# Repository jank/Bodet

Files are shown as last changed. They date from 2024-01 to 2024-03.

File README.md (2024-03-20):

# Bodet / T&N Flip Clock

I found a T&N (Telefonbau & Normalzeit) flip clock from the late 70ies/early 80ies. The clock is branded as T&N but was produced by Bodet.The model sticker on the inside says BT637.

I was inspired by this [Hackaday project](https://hackaday.io/project/186457-bodet-flip-clock-hacked-back-to-the-present) by iSax.

In this repo I documented the process on how I restored the clock and I also share design files and code.

## The Plan

- [x] check the clock is working: I connected the clock to a 12V power supply. Flipping + and - caused the clock to advance by one minute. So I considered it fully functional.

- [x] create spare tiles: I experimented with hard paper and plexiglas. In the end a rigid PVC material worked best. Cut out tiles using a Cricut.

- [x] program micro controller as clock driver: the code is ready. I added support for timezone and DST changes. When changing to DST, the clock will advance by 60 minutes, when changing to normal time, the clock will delay an hour.

- [ ] solder all parts together: Provide power from 230V AC, wire up and solder 230V AC to 12V DC converter, ESP32, and H-Bridge to drive clock.

## Implementing the Plan

As any good plan, mine changed as it was confronted with reality. I wrote down the different steps and detours I took. It might help you or my future self to avoid some detours.

### Check the Clock is Working

This was straight forward. Hooked up the clock to 12V supply and switched + and -. When the direction of the current was changed (flip +/-) the clock advanced by one minute.

The mechanics to drive the hour from the minute, the weekday and day of month from the hour, and the month from the day of month all worked. I did not check the leap year function. Will do that once all is wired up.

Seven of the hour and two of the minute tiles were missing.

### Create Spare Tiles

I first tried to get spare tiles from Bodet. To no surprise, they do not have them on stock anymore.

I used Fusion360 to design the tile (hour and minute tiles are identical for my clock). You can find the [Flip Clock Spare Part.dxf](/Spare%20Tiles/Flip%20Clock%20Spare%20Part.dxf) file in this repository.

Finding the right material for the tiles was a bit of a challenge. I found a local company, [Hema Kunststoff GmbH](https://maps.app.goo.gl/DWzyLc1jadHfFmLP6), specialized in milling plastic materials. They were very helpful in identifying the material: hard paper. It is a fiber composite material made of paper and a phenol-formaldehyde resin (phenolic resin).

I tried laser cutting the hard paper in a local maker space. Unfortunately, this did not work out. The power required to cut the material made it impossible to cut out the fine structure required to slot the tile into the clock wheel. This part is only 1mm thick. 

Next I tried to cut the tiles with a Cricut Air 2. But the hard paper was too rigid and the Cricut did not manage to cut through.

I asked the experts at Hema again. They would have milled the pieces for me, but given the required work hours, it would have cost around 10€ per tile.

After more research on the internet, I ordered the [rigid-PVC](https://www.modulor.de/en/rigid-pvc-opaque-coloured.html) from Modulor. This is a black, 0.3 mm thick material. It turned out to have similar flexibility/stiffness as the hard paper and I was able to cut it with the Cricut.

### Putting Numbers on the Spare Tiles.

On the internet I found the font 'folio' as recommendation for Bodet flip tiles. Doing test cuts, it quickly became apparent, that none of the myriads of fonts will do. The numbers of hours and minutes are of different size and slightly different shape. I have the impression, that these printing templates were rather hand-crafted based on a sans-serif template.

My wife helped me out here. She scanned tile that had parts of the missing numbers and reconstructed the shape in the Cricut design program. This required a lot of patience and I am happy that she took over.

We neded up picking white adhesive labels as the material to cut out the numbers. The result is quite impressive. From about a meter distance, it is impossible to distinguish the original tiles from the spare tiles.

### Control the Slave Clock

Due to the lack of a matching master clock, I want to run my slave clock using a microcontroller. 

My rough idea for the algorithm was:

* setup()
  * connect to wifi
  * connect to NTP server to keep system clock in sync

* loop() (e.g. every second)
  * check if a minute passed - remember result
  * check if DST switch happend, if yes, add or subtract 60 from tile buffer
  * if minute passed & tile buffer = 0
    * advance clock
  * if minute passed & tile buffer < 0
    * tile buffer++ // the wall clock is ahead of system time
  * if tile buffer > 0
    * advance clock // the wall clock is behind system time

Based on this [project](https://hackaday.io/project/186457-bodet-flip-clock-hacked-back-to-the-present) I purchased the following equipment for version 1:

* AZ-ATmega328DIP-Board Mikrocontroller Board ATmega16U2 8-bit Dev Board
* Prototyping Prototype Shield Mini Breadboard for UNO R3 (came with bundle)
* Jumper Wire cables M2M/ F2M / F2F 
* Double H-Bridge DC Motor Controller Board Modul AZ-L298N
* 220V AC/DC to 12V DC Mini converter

I was intruiged by the capability to run the board on 12V. That is also the current required to drive the clock motor and the H-Bridge. But I must have been a bit tired when I hit purchase. The ATmega board does not have WiFi on-board. Instead of buying a WiFi shield or a real-time-clock I decided to change to this option:

* ESP32 NodeMCU Module WLAN WiFi Development Board | Dev Kit C V2
* Jumper Wire cables M2M/ F2M / F2F 

Luckily, the H-Bridge provides a 5V power out pin. So I can connect the DC Mini converter to the H-Bridge and power the ESP32 from the 5V output. No need for an additional step-down component.

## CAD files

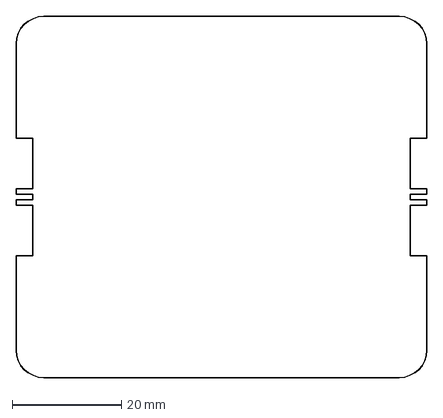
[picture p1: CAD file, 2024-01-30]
Bodet Flip Clock Double Tile.dxf
75.0 x 66.0 mm

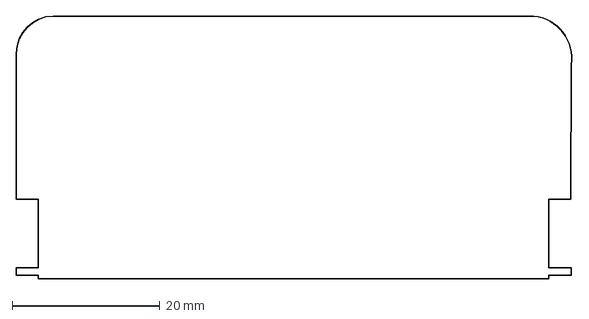
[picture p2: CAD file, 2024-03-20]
Spare Tiles/Flip Clock Spare Part.dxf
75.3 x 35.5 mm

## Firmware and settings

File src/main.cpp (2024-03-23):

#include <Arduino.h>
#include <WiFi.h>

// Mode configuration - uncomment to run in bare bone mode
// will advance the tile every 2.5 sec.
//#define BARE_BONE_MODE

// Log configuration - comment out to get rid of any serial out
#define DEBUG_ENABLED
#ifdef DEBUG_ENABLED
#define DEBUG_PRINTLN(x) Serial.println(x)
#define DEBUG_PRINT(x) Serial.print(x)
#else
#define DEBUG_PRINTLN(x)
#define DEBUG_PRINT(x)
#endif

// Board parameters
static const int enable_pin = 21;
static const int input1_pin = 23;
static const int input2_pin = 22;

// WiFi parameters
static const char *ssid = "Alternativlos";
static const char *password = "Mannheim";

// NTP parameters
static const char *ntp_pool = "de.pool.ntp.org";
static const char *cet_tz = "CET-1CEST,M3.5.0/02,M10.5.0/03";

/** Global varibales */
bool setup_completed = false;
// used to alternate DC flow
bool direction = false;
// Keeps the number of flips to perform on the minute tile to adjust for DST changes.
// Values can be positive, 0, or negativ.
// It is assumed that the main loop is performed at a higher frequency than a minute (e.g. once every 500ms)
// Positive values indicate the number of minutes to advance the clock.
// A 0 indicates that the clock does not need to get changed.
// Negative values indicate that the clock must be paused for -n minutes.
// Positive values larger than one and negative values can be used to perform summer/winter time adjustment.
int dst_adjustment = 0;
// keeps the last time assumed to be displayed on clock
struct tm clock_time;

/**
 * Setup NTP and set local time zone
 */
void initTime(String timezone)
{
  struct tm timeinfo;

  DEBUG_PRINTLN("Setting up time");
  // First connect to NTP server, with 0 TZ offset
  configTime(0, 0, ntp_pool);
  int ntp_retries = 3;
  while (ntp_retries > 0)
  {
    if (!getLocalTime(&timeinfo))
    {
#ifdef DEBUG_ENABLED
      Serial.println("  Failed to obtain time");
      Serial.print("  Retry attempts left: ");
      Serial.println(ntp_retries);
#endif
      ntp_retries -= 1;
    }
    else
    {
#ifdef DEBUG_ENABLED
      Serial.println("  Got time from NTP");
      Serial.printf("  Setting Timezone to %s\n", timezone.c_str());
#endif
      // Set the timezone
      setenv("TZ", timezone.c_str(), 1);
      tzset();
      break;
    }
  }
}

// Function to alternate the direction of current to drive the clock motor
void advanceMinuteTile()
{
  direction = !direction;
#ifdef DEBUG_ENABLED
  if (direction)
  {
    Serial.println("DC >>>");
  }
  else
  {
    Serial.println("DC <<<");
  }
#endif
  digitalWrite(input1_pin, direction);
  digitalWrite(input2_pin, !direction);
  digitalWrite(enable_pin, HIGH); // Enable the motor
}

/**
 * Setup Bodet Clock Driver
 */
// cppcheck-suppress unusedFunction
void setup()
{
  Serial.begin(115200);
  // Initializte the GPIO pins as output and set voltage
  pinMode(enable_pin, OUTPUT);
  pinMode(input1_pin, OUTPUT);
  pinMode(input2_pin, OUTPUT);
  //better without? advanceMinuteTile();
  // just plugin in clock a few seconds after the minute switched to what is shown on the clock.

#ifdef BARE_BONE_MODE
  return;
#endif

  // Connect to WiFi network
  WiFi.begin(ssid, password);
  DEBUG_PRINT("Connecting to WiFi.");
  while (WiFi.status() != WL_CONNECTED)
  {
    delay(200);
    DEBUG_PRINT(".");
  }
  DEBUG_PRINTLN("");
  DEBUG_PRINTLN("Connected to WiFi.");
  DEBUG_PRINT("IP Address: ");
  DEBUG_PRINTLN(WiFi.localIP());

  // Configure NTP and clock time
  initTime(cet_tz);
  if (!getLocalTime(&clock_time))
  {
    DEBUG_PRINTLN("Failed to obtain clock time");
    return;
  }

#ifdef DEBUG_ENABLED
  Serial.print("Clock time is: ");
  Serial.println(&clock_time, "%A, %B %d %Y %H:%M zone %Z %z ");
  Serial.println("Setup completed.");
#endif

  setup_completed = true;
}

/**
* Loop for bare bone testing mode.
*/
void bare_bone_loop()
{
  DEBUG_PRINT("Advance Tile in bare bone mode.");
  advanceMinuteTile();
  delay(500);
}

/**
 * Main loop driving the minute tile flip. This loop should be run more often than once per minute.
 * Otherwise the calcuation of minutes to flip will not work.
 */
void main_loop()
{
  // check if time advanced by a minute
  bool advanced_by_minute = false;
  struct tm system_time;
  if (!getLocalTime(&system_time))
  {
    DEBUG_PRINTLN("Failed to obtain new system time. Using last clock time.");
    system_time = clock_time;
  }
  if (system_time.tm_min != clock_time.tm_min)
  {
    advanced_by_minute = true;
  }

  // check for DST change
  if (system_time.tm_isdst && !clock_time.tm_isdst)
  {
    // switch to summer time (DST / CEST)
    dst_adjustment += 60;
  }
  else if (!system_time.tm_isdst && clock_time.tm_isdst)
  {
    // switch to winter time (non-DST / CET)
    dst_adjustment -= 60;
  }

  // advance the clock per minute or to catch up after switch to DST
  if (advanced_by_minute)
  {
#ifdef DEBUG_ENABLED
    Serial.print("System time: ");
    Serial.println(&system_time, "%A, %B %d %Y %H:%M:%S zone %Z %z ");
    Serial.print("Clock time : ");
    Serial.println(&clock_time, "%A, %B %d %Y %H:%M:%S zone %Z %z ");
    Serial.print("Advance minute: ");
    Serial.print(advanced_by_minute);
    Serial.print("DST adjustments: ");
    Serial.println(dst_adjustment);
#endif
    // set clock time to system time
    clock_time = system_time;

    if (dst_adjustment < 0)
    {
      // clock time is ahead of system time (DST to normal), do not flip minute tile.
      dst_adjustment += 1;
#ifdef DEBUG_ENABLED
      Serial.print(" > DST adjustment: *not* advancing minute, left: ");
      Serial.println(dst_adjustment);
#endif
    }
    else
    {
      // clock time is in sync (normal) or behind system time, flip minute tile.
      advanceMinuteTile();
      // do not reduce dst_adjustment as this is a regular minute
    }
  }
  else if (dst_adjustment > 0)
  {
    // if clock time is running behind (DST change), catch up
    advanceMinuteTile();
    dst_adjustment -= 1;
#ifdef DEBUG_ENABLED
    Serial.print(" > DST adjustment: advancing minute, delta left: ");
    Serial.println(dst_adjustment);
#endif
  }

  // 500ms delay is the result of tests with the clock.
  // This results in tiles quickly for testing or during DST switch.
  delay(500);
}

// cppcheck-suppress unusedFunction
void loop()
{
  // To allow testing without WiFi and/or NTP
  if (!setup_completed)
  {
    bare_bone_loop();
    return;
  }
  else {
    main_loop();
  }  
}

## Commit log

2024-01-28 DXF file with tile shape
    [Bodet Flip Clock Tile.dxf]
2024-01-30 Double tile version for easier application of numbers
    [Bodet Flip Clock Double Tile.dxf]
2024-01-31 Update README.md
    results from laser cutting hard paper
2024-03-20 Updated Readme with current project progress
2024-03-20 Added Spare Tile DXF file to design subfolder
    [Bodet Flip Clock Tile.dxf, Flip Clock Spare Part.dxf]
2024-03-20 Added ESP32 code
2024-03-22 Bug fix: regular minute advance and DST catch-up were missing a delay.
    [main.cpp]
2024-03-22 added missing config parameter, reintroduced initial output on H-Bridge
    [main.cpp]
